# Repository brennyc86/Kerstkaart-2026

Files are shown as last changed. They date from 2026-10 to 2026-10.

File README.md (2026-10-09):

# Kerstkaart 2026 – Rudolf het rendier

Een printplaat in de vorm van een rendier (96 × 98 mm) met 42 piepkleine NeoPixels. De ATtiny is het **oog**, het knopje is de **neus**,
de overige onderdelen zijn wimpers en wenkbrauw. Op de voorkant staat de kerstboodschap *Zalig Kerstfeest en een gelukkig 2027*.

| Voorkant | Achterkant |
|---|---|
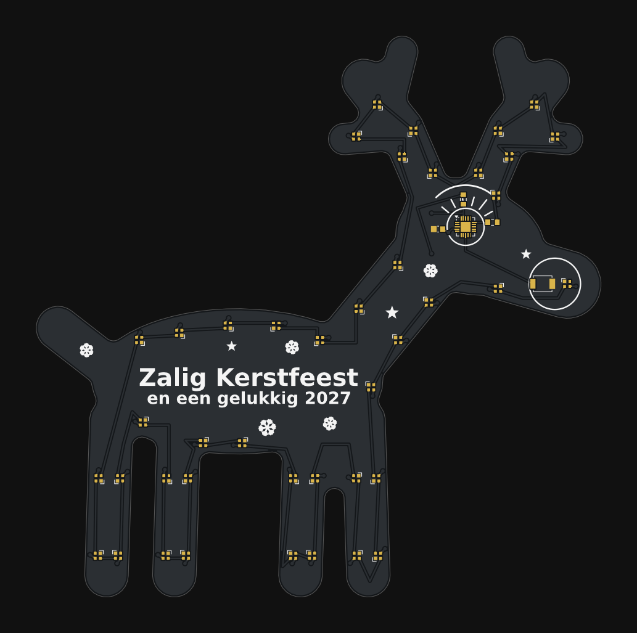
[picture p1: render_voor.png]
voor
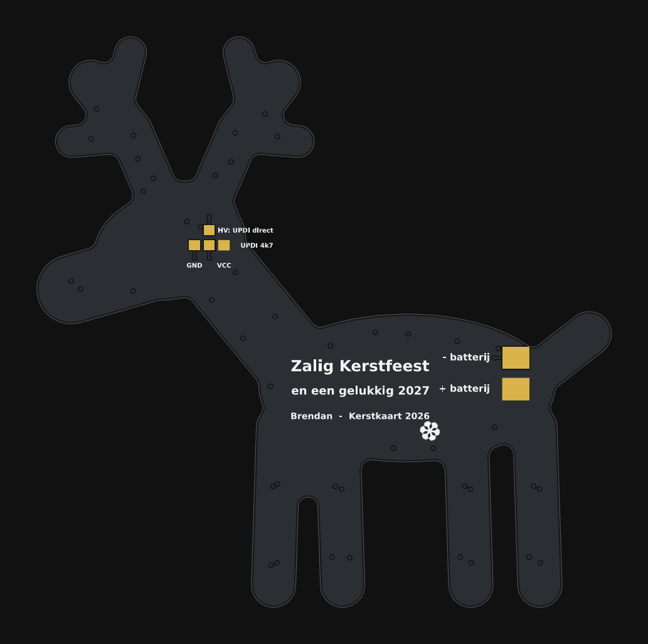
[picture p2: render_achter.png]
achter
|  |  |

## Ontwerp

| Onderdeel | Type | LCSC |
|---|---|---|
| 42 × LED | SK6805-EC15, 1,5 × 1,5 mm NeoPixel (5 mA, 3,7–5,5 V) | C2890035 |
| Oog | ATtiny1616-MNR, VQFN-20 3×3 mm | C507118 |
| Neus | Omron B3U-1000P, 3 × 2,5 mm tactknopje | C231329 |
| C1 / R1 / R2 | 100 nF / 330 Ω (data) / 4,7 kΩ (UPDI), alle 0603 | C14663 / C23138 / C23162 |

* **Chip als oog:** een witte silkring maakt van de QFN de pupil; C1, R1 en R2 staan rond de ring als wimpers, met een wenkbrauw erboven.
* **Knop als neus:** de B3U zit in de snuit, met de rode neus-LED ernaast; een silkring om beide. Indrukken = volgend lichtprogramma, lang indrukken = helderheid.
* **Geweien identiek:** gewei A is een exacte spiegel van gewei B (elk 5 LED's); de firmware gebruikt `gewei_rang()` zodat alle effecten links en rechts gelijk lopen.
* **LED's recht:** alle LED's staan in 0°/90°/180°/270° t.o.v. de footprint.
* **Batterij (3 × AAA, ≥ 4,5 V):** grote koperpads `+` / `-` op de achterkant (4,6 × 3,8 mm) om draden of een batterijhouder op te solderen. De JST-connector is vervallen.
* **Programmeren, op de achterkant:** rij `GND – UPDI 4k7 – VCC` met UPDI in het midden (via R2), en een aparte pad **`HV: UPDI direct`** die rechtstreeks aan de UPDI-pen hangt voor hoogspanningsprogrammering.
* **Pinnen** (uit het KiCad-symbool): pen 3 GND, 4 VCC, 8 PA7 = knop, 15 PC0 = data, 19 UPDI, 21 = EP (GND).

* **Koper tot de rand:** beide lagen zijn gevuld tot 0,3 mm van de rand (voorkant GND, achterkant VCC), ook smalle randstroken. Losse stukken zijn zwevend koper, puur optisch.
* **GND-via's:** bij elke GND-aansluiting (alle LED's, ATtiny, C1, knop) zit een via vlak ernaast. De onderlaag is VCC-vlak, dus elke via heeft daar een klein eilandje met vrije ruimte eromheen.

## Kleurkeuze (1 kleur silk)
Zwart soldeermasker, witte silk, ENIG-goud: de LED's lichten het mooist op, de boodschap is goed leesbaar en het goud accentueert de blanke pads (`HV`, `UPDI`, batterijpads, oog en neus).
Alternatief: rood masker + witte silk. Een volledig kleuren-silkscreen is een EasyEDA Pro-functie die ik hier niet kan genereren.

## Bestanden

| Pad | Inhoud |
|---|---|
| `kerstkaart_2026_gerber.zip` | Gerbers + boorbestand (JLCPCB) |
| `productie/BOM_kerstkaart_2026.csv`, `productie/CPL_kerstkaart_2026.csv` | Stuklijst en plaatsingsbestand |
| `kerstkaart2026.kicad_pcb` | KiCad-bord (KiCad 10-formaat, **ongetest**, de Gerbers zijn leidend) |
| `footprints/` | De KiCad-bibliotheekfootprints van alle onderdelen |
| `firmware/kerstkaart2026/` | Arduino-sketch (megaTinyCore + tinyNeoPixel) + `leds.h` |
| `gen.py`, `shape.py`, `ketting.py`, `kunst.py`, `sexp.py` | Generator: silhouet, LED-volgorde, silk-kunst → Gerbers, BOM, CPL, renders, `leds.h` |

## Nog controleren
* **Gerbers/CPL:** ingelezen met `gerbonara` (8 lagen + boorbestand herkend), maar niet in KiCad of in JLC's viewer bekeken. Controleer daar de **rotatie** van LED's, U1, knop en connector (JLC wijkt soms 90°/180° af), en of JLC de SK6805-EC15 en B3U-1000P op voorraad heeft.
* **Mijn eigen controle** (spoor/pad-afstand 0,2 mm, randafstand 0,4 mm, GND en VCC elk één samenhangend vlak) is geen volledige DRC.
* **SK6805-EC15:** pinout uit de datasheet (1 DIN, 2 VDD, 3 DOUT, 4 GND, GND linksboven gezien van boven); de padmaten (0,5 × 0,5 mm op 0,9 mm) komen uit de KiCad EC15-footprint, niet uit de datasheet-afbeelding. Het type is dimmer (5 mA) en heeft minstens 3,7 V nodig: een bijna lege batterij laat de LED's eerder uitvallen dan de chip.
* De 0603-LCSC-nummers zijn niet apart geverifieerd. De 5-LED-geweien laten de binnenste zijtak onverlicht.
* Firmware alleen op syntax gecontroleerd, niet op een echte ATtiny.

## Licentie en bronnen
De footprints in `footprints/` komen uit de KiCad-bibliotheken (CC-BY-SA 4.0 met uitzondering voor het gebruik in ontwerpen). De overige bestanden zijn van Brendan.

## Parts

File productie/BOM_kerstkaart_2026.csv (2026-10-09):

Comment | Designator | Footprint | LCSC Part #
ATtiny1616-MNR (VQFN-20) | U1 | VQFN-20-1EP_3x3mm_P0.4mm_EP1.7x1.7mm | C507118
100nF 0603 | C1 | C_0603_1608Metric | C14663
330R 0603 | R1 | R_0603_1608Metric | C23138
4.7k 0603 | R2 | R_0603_1608Metric | C23162
B3U-1000P | SW1 | SW_SPST_B3U-1000P | C231329
SK6805-EC15 | D1,D2,D3,D4,D5,D6,D7,D8,D9,D10,D11,D12,D13,D14,D15,D16,D17,D18,D19,D20,D21,D22,D23,D24,D25,D26,D27,D28,D29,D30,D31,D32,D33,D34,D35,D36,D37,D38,D39,D40,D41,D42 | LED_SK6812_EC15_1.5x1.5mm | C2890035

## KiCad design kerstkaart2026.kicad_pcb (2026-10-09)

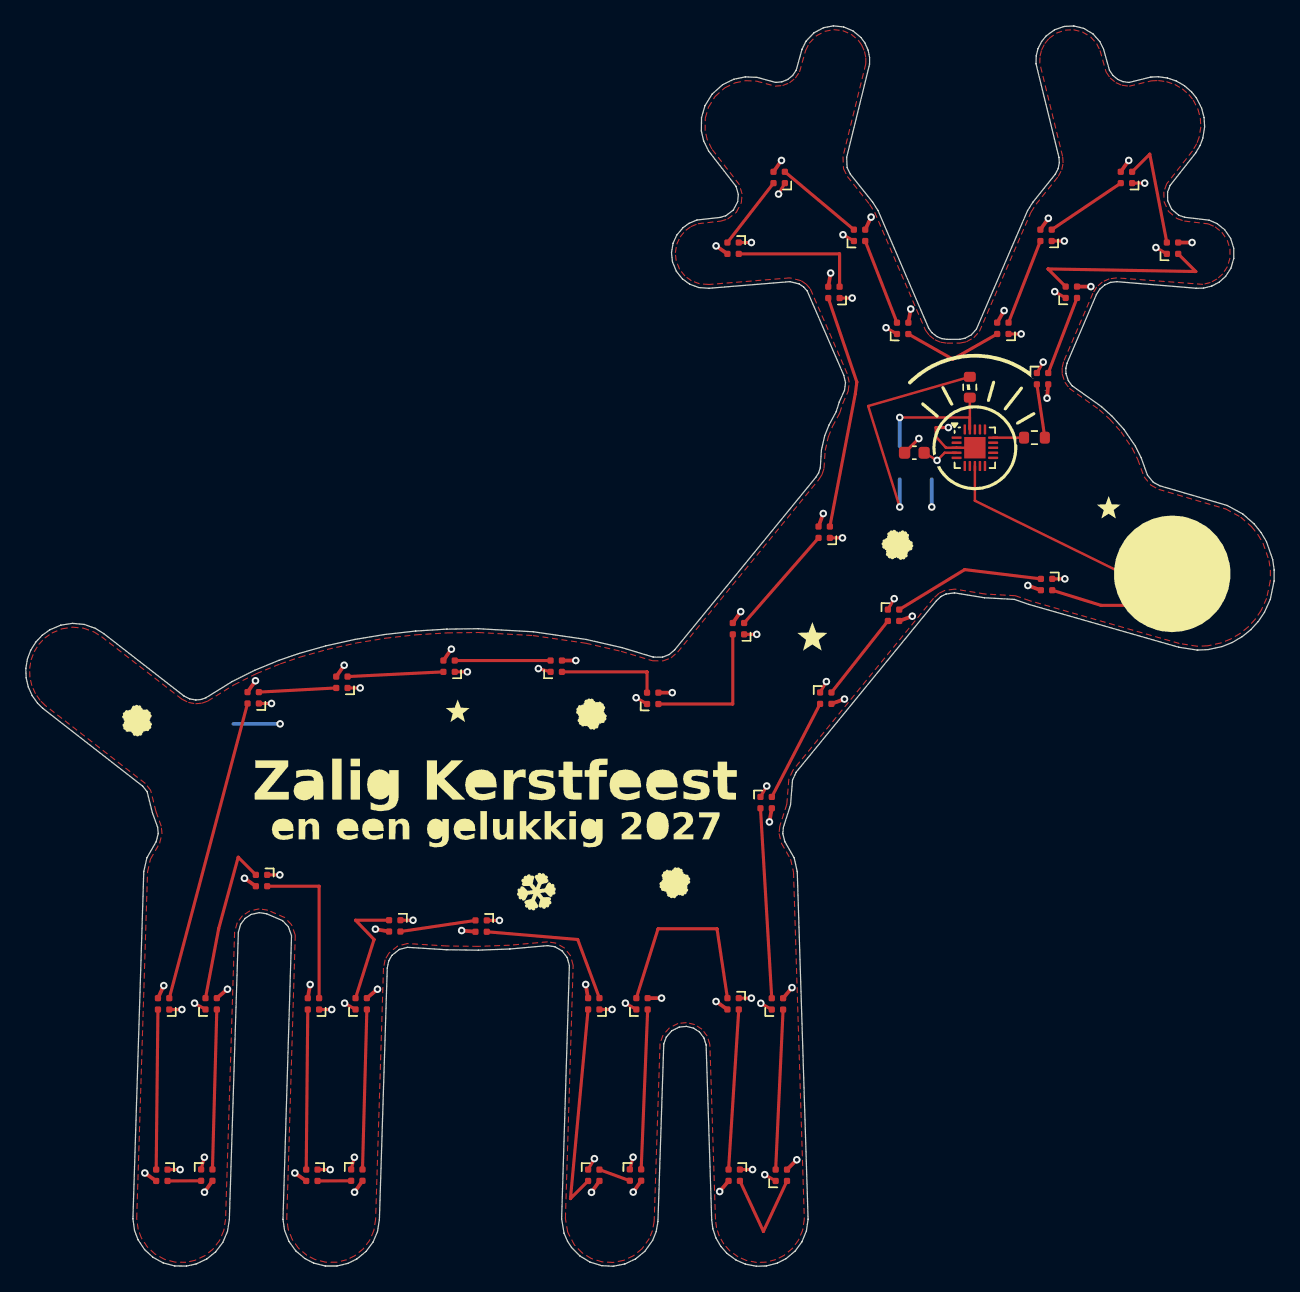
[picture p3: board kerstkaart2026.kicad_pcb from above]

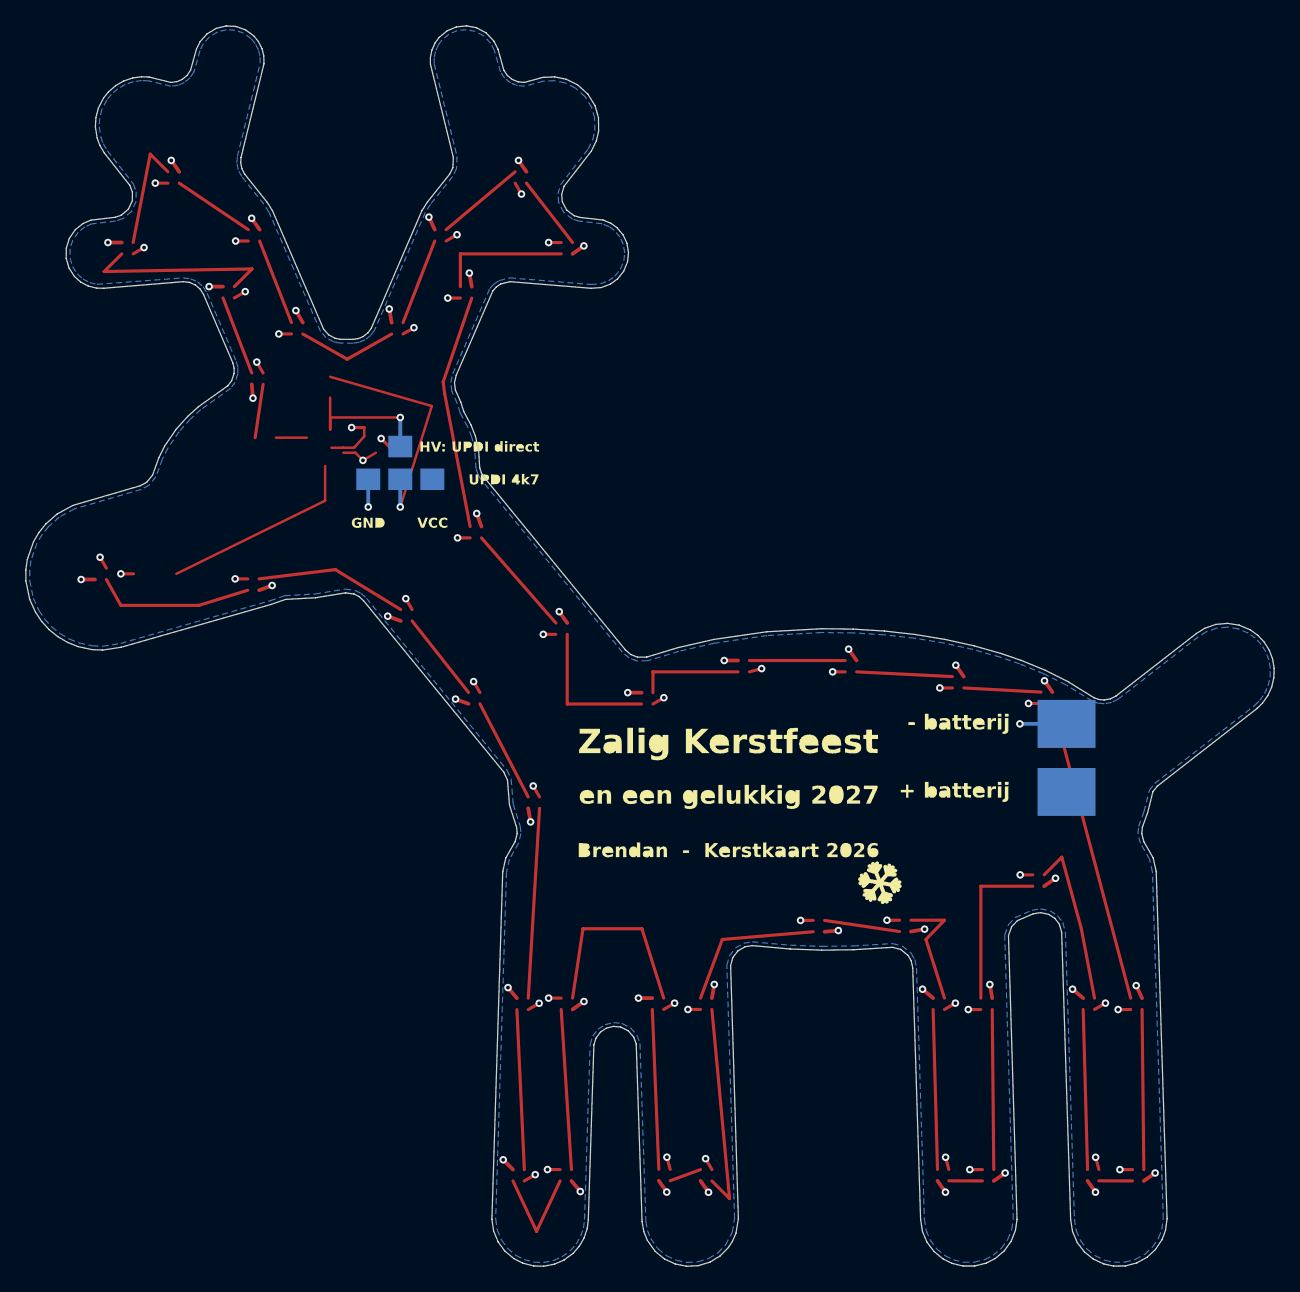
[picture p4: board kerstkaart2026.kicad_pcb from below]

Board: 2 copper layers, 99.0 x 98.4 mm, 53 parts (6 on the bottom side), 48 nets.

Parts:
C1: 100nF 0603; C_0603_1608Metric
D1, D2, D3, D4, D5, D6, D7, D8, D9, D10, D11, D12, D13, D14, D15, D16, D17, D18, D19, D20, D21, D22, D23, D24, D25, D26, D27, D28, D29, D30, D31, D32, D33, D34, D35, D36, D37, D38, D39, D40, D41, D42: SK6805-EC15; LED_SK6812_EC15_1.5x1.5mm
R1: 330R 0603; R_0603_1608Metric
R2: 4.7k 0603; R_0603_1608Metric
SW1: B3U-1000P; SW_SPST_B3U-1000P
TP_BT+: Pad_BT+
TP_BT-: Pad_BT-
TP_GND: Pad_GND
TP_HV: Pad_HV
TP_UPDI: Pad_UPDI
TP_VCC: Pad_VCC
U1: ATtiny1616-MNR (VQFN-20); VQFN-20-1EP_3x3mm_P0.4mm_EP1.7x1.7mm

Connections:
BTN: SW1.1, U1.8
D1: D1.3, D2.1
D2: D2.3, D3.1
D3: D3.3, D4.1
D4: D4.3, D5.1
D5: D5.3, D6.1
D6: D6.3, D7.1
D7: D7.3, D8.1
D8: D8.3, D9.1
D9: D9.3, D10.1
D10: D10.3, D11.1
D11: D11.3, D12.1
D12: D12.3, D13.1
D13: D13.3, D14.1
D14: D14.3, D15.1
D15: D15.3, D16.1
D16: D16.3, D17.1
D17: D17.3, D18.1
D18: D18.3, D19.1
D19: D19.3, D20.1
D20: D20.3, D21.1
D21: D21.3, D22.1
D22: D22.3, D23.1
D23: D23.3, D24.1
D24: D24.3, D25.1
D25: D25.3, D26.1
D26: D26.3, D27.1
D27: D27.3, D28.1
D28: D28.3, D29.1
D29: D29.3, D30.1
D30: D30.3, D31.1
D31: D31.3, D32.1
D32: D32.3, D33.1
D33: D33.3, D34.1
D34: D34.3, D35.1
D35: D35.3, D36.1
D36: D36.3, D37.1
D37: D37.3, D38.1
D38: D38.3, D39.1
D39: D39.3, D40.1
D40: D40.3, D41.1
D41: D41.3, D42.1
DATA0: R1.1, U1.15
DATA1: D1.1, R1.2
GND: C1.1, D1.4, D2.4, D3.4, D4.4, D5.4, D6.4, D7.4, D8.4, D9.4, D10.4, D11.4, D12.4, D13.4, D14.4, D15.4, D16.4, D17.4, D18.4, D19.4, D20.4, D21.4, D22.4, D23.4, D24.4, D25.4, D26.4, D27.4, D28.4, D29.4, D30.4, D31.4, D32.4, D33.4, D34.4, D35.4, D36.4, D37.4, D38.4, D39.4, D40.4, D41.4, D42.4, SW1.2, TP_BT-.1, TP_GND.1, U1.3, U1.21
UPDI0: R2.1, TP_HV.1, U1.19
UPDI_R: R2.2, TP_UPDI.1
VCC: C1.2, D1.2, D2.2, D3.2, D4.2, D5.2, D6.2, D7.2, D8.2, D9.2, D10.2, D11.2, D12.2, D13.2, D14.2, D15.2, D16.2, D17.2, D18.2, D19.2, D20.2, D21.2, D22.2, D23.2, D24.2, D25.2, D26.2, D27.2, D28.2, D29.2, D30.2, D31.2, D32.2, D33.2, D34.2, D35.2, D36.2, D37.2, D38.2, D39.2, D40.2, D41.2, D42.2, TP_BT+.1, TP_VCC.1, U1.4

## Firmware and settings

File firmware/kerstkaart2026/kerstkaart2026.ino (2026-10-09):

// Kerstkaart 2026 - Rudolf het rendier
// ATtiny1616-M (VQFN-20) @ 16 MHz (megaTinyCore): de chip is het oog van Rudolf.
// SK6805-EC15 NeoPixels aan PC0 (pen 15); knop (= neus) op PA7 (pen 8, naar GND)
// Korte druk = volgend programma, lang (>0,8 s) = helderheid wisselen.
#include <tinyNeoPixel.h>
#include <EEPROM.h>
#include "leds.h"

#define PIN_LEDS  PIN_PC0
#define PIN_KNOP  PIN_PA7
#define N_MODUS   7

tinyNeoPixel pix = tinyNeoPixel(N_LED, PIN_LEDS, NEO_GRB + NEO_KHZ800);

const uint8_t HELDER[3] = {40, 100, 220};
uint8_t helderheid = 0;
uint8_t modus = 0;
unsigned long t_vorig = 0;

uint8_t lx(uint8_t i) { return pgm_read_byte(&LED_X[i]); }
uint8_t ly(uint8_t i) { return pgm_read_byte(&LED_Y[i]); }

// kleur met factor f (0..255)
uint32_t kleur(uint8_t r, uint8_t g, uint8_t b, uint8_t f = 255) {
  return pix.Color((uint16_t)r * f / 255, (uint16_t)g * f / 255, (uint16_t)b * f / 255);
}
// zachte golf 0..255
uint8_t golf(uint16_t t, uint16_t periode) {
  uint16_t x = (t % periode) * 512UL / periode;
  return x < 256 ? x : 511 - x;
}
void wis() { pix.clear(); }

void toon() {
  pix.setBrightness(HELDER[helderheid]);
  pix.show();
}

// 0: Rudolf - gloeiende neus, twinkelend goud, knipperend oog
void m_rudolf(unsigned long t) {
  for (uint8_t i = 0; i < N_LED; i++) {
    uint8_t f = 40 + golf(t / 8 + i * 37, 1500) / 4;
    pix.setPixelColor(i, kleur(255, 150, 20, f / 2));
  }
  for (uint8_t i = GEWEI_B_VAN; i <= GEWEI_A_TOT; i++) pix.setPixelColor(i, kleur(255, 240, 200, 60 + golf(t / 6 + gewei_rang(i) * 50, 2000) / 3));
  pix.setPixelColor(NEUS, kleur(255, 0, 0, 60 + golf(t / 3, 1600) * 3 / 4));
}
// 1: Vliegende komeet langs de hele keten
void m_komeet(unsigned long t) {
  wis();
  int kop = (t / 55) % (N_LED + 10);
  for (uint8_t s = 0; s < 10; s++) {
    int i = kop - s;
    if (i >= 0 && i < N_LED) pix.setPixelColor(i, kleur(200, 220, 255, 255 >> (s / 2 + (s > 0))));
  }
  // geweien: beide krijgen exact dezelfde komeet (op spiegel-positie), niet na elkaar
  int rk = (kop - GEWEI_B_VAN) / 2;                 // 'kop' loopt door beide geweien, rank door het gewei
  for (uint8_t i = GEWEI_B_VAN; i <= GEWEI_A_TOT; i++) {
    int d = rk - gewei_rang(i);
    pix.setPixelColor(i, (d >= 0 && d < 5) ? kleur(200, 220, 255, 255 >> d) : 0);
  }
  pix.setPixelColor(NEUS, kleur(255, 0, 0, 200));
}
// 2: Sneeuwval
void m_sneeuw(unsigned long t) {
  static uint8_t vlok[N_LED];
  static unsigned long last = 0;
  if (t - last > 90) {
    last = t;
    for (uint8_t i = 0; i < N_LED; i++) vlok[i] = vlok[i] > 24 ? vlok[i] - 24 : 0;
    vlok[random(N_LED)] = 255; vlok[random(N_LED)] = 180;
  }
  for (uint8_t i = 0; i < N_LED; i++) { uint8_t w = vlok[i] > 60 ? vlok[i] / 2 : 0; uint8_t b = 25 + vlok[i] / 4; pix.setPixelColor(i, pix.Color(w, w + b / 2, min(255, w + b + 40))); }
  pix.setPixelColor(NEUS, kleur(255, 0, 0, 80));
}
// 3: Noorderlicht - kleurgolf over de x-positie
void m_noorder(unsigned long t) {
  for (uint8_t i = 0; i < N_LED; i++) {
    uint8_t a = golf(t / 10 + lx(i) * 5 + ly(i) * 2, 2400);
    uint8_t b = golf(t / 14 + lx(i) * 3, 3200);
    pix.setPixelColor(i, kleur(a / 3, 40 + a / 2, 255 - b / 2, 140));
  }
  pix.setPixelColor(NEUS, kleur(255, 0, 0, 90 + golf(t / 3, 1600) / 2));
}
// 4: Gewei-kerstlichtjes loopverlicht, lijf warm
void m_gewei(unsigned long t) {
  const uint8_t kl[4][3] = {{255, 0, 0}, {0, 255, 0}, {255, 180, 0}, {0, 80, 255}};
  for (uint8_t i = 0; i < N_LED; i++) pix.setPixelColor(i, kleur(255, 120, 10, 35));
  uint8_t stap = (t / 350) % 4;
  for (uint8_t i = GEWEI_B_VAN; i <= GEWEI_A_TOT; i++) {
    const uint8_t *c = kl[(gewei_rang(i) + stap) % 4];   // beide geweien lopen gelijk
    pix.setPixelColor(i, kleur(c[0], c[1], c[2], 220));
  }
  pix.setPixelColor(NEUS, kleur(255, 0, 0, 255));
}
// 5: Ademend warm-wit (rustig)
void m_adem(unsigned long t) {
  uint8_t f = 20 + golf(t / 6, 4000) * 3 / 4;
  for (uint8_t i = 0; i < N_LED; i++) pix.setPixelColor(i, kleur(255, 170, 70, f));
  pix.setPixelColor(NEUS, kleur(255, 0, 0, 40 + f));
}
// 6: Neus-alarm: neus pulseert, kop volgt, rest dim - Rudolf leidt de slee
void m_neus(unsigned long t) {
  wis();
  uint8_t f = golf(t / 2, 1200);
  pix.setPixelColor(KOP, kleur(255, 40, 0, f / 6));
  pix.setPixelColor(KIN, kleur(255, 40, 0, f / 6));
  pix.setPixelColor(NEUS, kleur(255, 0, 0, 30 + f * 7 / 8));
  for (uint8_t i = GEWEI_B_VAN; i <= GEWEI_A_TOT; i++) if (random(40) == 0) pix.setPixelColor(i, kleur(255, 255, 255, 200));
}

void knop_wacht_los() { while (digitalRead(PIN_KNOP) == LOW) delay(10); }

void setup() {
  pix.begin();
  pinMode(PIN_KNOP, INPUT_PULLUP);
  modus = EEPROM.read(0) % N_MODUS;
  helderheid = EEPROM.read(1) % 3;
  randomSeed(analogRead(PIN_PA4));
}

void loop() {
  if (digitalRead(PIN_KNOP) == LOW) {
    unsigned long start = millis();
    while (digitalRead(PIN_KNOP) == LOW && millis() - start < 800) delay(10);
    if (digitalRead(PIN_KNOP) == LOW) {          // lang
      helderheid = (helderheid + 1) % 3;
      EEPROM.update(1, helderheid);
    } else {                                      // kort
      modus = (modus + 1) % N_MODUS;
      EEPROM.update(0, modus);
    }
    knop_wacht_los(); delay(30);
  }
  unsigned long t = millis();
  if (t - t_vorig < 20) return;                   // ~50 beelden/s
  t_vorig = t;
  switch (modus) {
    case 0: m_rudolf(t); break;
    case 1: m_komeet(t); break;
    case 2: m_sneeuw(t); break;
    case 3: m_noorder(t); break;
    case 4: m_gewei(t); break;
    case 5: m_adem(t); break;
    default: m_neus(t); break;
  }
  toon();
}

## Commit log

2026-10-09 Kerstkaart 2026: rendier-PCB, firmware en generator
    [kerstkaart2026.kicad_pcb]
2026-10-09 Kerstkaart 2026 v2: echte footprints, QFN, achterpads (UPDI direct + 4k7), knop, symmetrische geweien, boodschap, Gerbers/BOM/CPL
    [BOM_kerstkaart_2026.csv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]
2026-10-09 Fix: dubbele footprint-header in KiCad-bestand (parsefout regel 62)
    [kerstkaart2026.kicad_pcb]
2026-10-09 Kerstkaart 2026 v3: SK6805-EC15 LED's, chip als oog, knop als neus, grote batterijpads + JST, rechte LED's, symmetrische geweien
    [BOM_kerstkaart_2026.csv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]
2026-10-09 v4: JST weg, LED-padafstanden gerepareerd, koper tot aan de rand
    [BOM_kerstkaart_2026.csv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]
2026-10-09 v5: GND-via's, tekst vrij van LED's, randkoper, geen ref-teksten in KiCad
    [kerstkaart2026.kicad_pcb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]
